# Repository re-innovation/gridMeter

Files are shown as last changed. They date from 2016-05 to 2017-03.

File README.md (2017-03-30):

# gridMeter
A National Grid frequency monitor for visualising power flows on the national grid

# Overview

# Collaborators
* James Fowkes - Software and PCB design v1
* Matt Little - PCB design v2 and Hardware

# PCB
This holds the PCB files done using KiCAD
http://kicad-pcb.org/

# Software
This holds the software. Uploaded via the Arduino IDE.
This is programmed to an ATTiny84
It requires

# Hardware
This holds the mechanical files for the enclosure.

# To DO

- Update PCB design with changes
- Enclosure design - version 1 done

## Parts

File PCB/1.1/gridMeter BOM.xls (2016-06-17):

Reference | Quantity | Value | Footprint | Datasheet | Manufacturer | Manufacturer Part No | Supplier 1 | Supplier 1 Part No | Cost | Description
C1 C4 C5 | 3 | 100n | Capacitors_ThroughHole:C_Rect_L7_W2.5_P5
C2 C3 | 2 | 220u | Capacitors_ThroughHole:C_Radial_D6.3_L11.2_P2.5
CON1 | 1 | AC POWER | REInnovationFootprint:DC_Power_2_1 | http://www.rapidonline.com/pdf/20-0970.pdf | TruConnect |  | Rapid | 20-0970 | 0.19 | 2.1mm Barrell Jack
D1 D2 D3 D4 D5 D6 | 6 | 1N400x | Diodes_ThroughHole:Diode_DO-41_SOD81_Horizontal_RM10
IC1 | 1 | ATTINY84A-PU | Housings_DIP:DIP-14_W7.62mm | http://docs-europe.electrocomponents.com/webdocs/0fa2/0900766b80fa26b4.pdf | Atmel | ATTINY84A-PU | RS | 738-0684 | 1.05
P1 | 1 | STEPPER
P2 | 1 | AC POWER | REInnovationFootprint:TH_CONN_2W
P3 | 1 | MOTOR | gridMeter:XHP-5
P4 | 1 | ISP | Pin_Headers:Pin_Header_Straight_2x03
P5 | 1 | PCB
P6 | 1 | LOGO1 | CuriousElectric2:CuriousElectric_flat_12mm
P7 | 1 | Enclosure
P8 | 1 | LOGO2 | CuriousElectric2:CuriousElectric_globe_10mm
R2 | 1 | 330R | Resistors_ThroughHole:Resistor_Horizontal_RM10mm
R1 R3 R4 | 3 | 10K | Resistors_ThroughHole:Resistor_Horizontal_RM10mm
U1 | 1 | MCP170-3_3V | matts_components:TO92-MCP1700 | http://docs-europe.electrocomponents.com/webdocs/137e/0900766b8137eacf.pdf | Microchip | MCP1700-3302E/TO | RS | 403-888 | 0.253 | LDO 3.3V 100mA
U2 | 1 | TCXO_SMD_4P | gridMeter:FOX924 |  | Fox | FOX924B-16.000 | Aliexpress | http://www.aliexpress.com/item/Hot-selling-original-15PCS-FOX924B-16-000-Oscillator-TCXO-16MHz-1-5ppm-2-5ppm-Stability/32668179196.html | 0.6 | 12MHz TCO SMD
U3 | 1 | TCRT5000 | gridMeter:TCRT5000 |  |  | TCRT5000L | Aliexpress | http://www.aliexpress.com/item/Free-Shipping-100-pcs-TCRT5000L-TCRT5000-Reflective-Infrared-Optical-Sensor-Photoelectric-Switches/1933011720.html | 0.15 | Opto-reflective IR sensor
U4 | 1 | 7805 | TO_SOT_Packages_THT:TO-220_Neutral123_Horizontal | http://docs-europe.electrocomponents.com/webdocs/12cf/0900766b812cfcbe.pdf | Fairchild | LM7805ACT | RS | 806-2839 | 0.327 | 1A 5V regulator.
U5 | 1 | ULN2003 | Housings_DIP:DIP-16_W7.62mm_LongPads | http://docs-europe.electrocomponents.com/webdocs/1294/0900766b81294fa6.pdf | Toshiba | ULN2003APG | RS | 796-5320 | 0.151 | Darlington transistor array

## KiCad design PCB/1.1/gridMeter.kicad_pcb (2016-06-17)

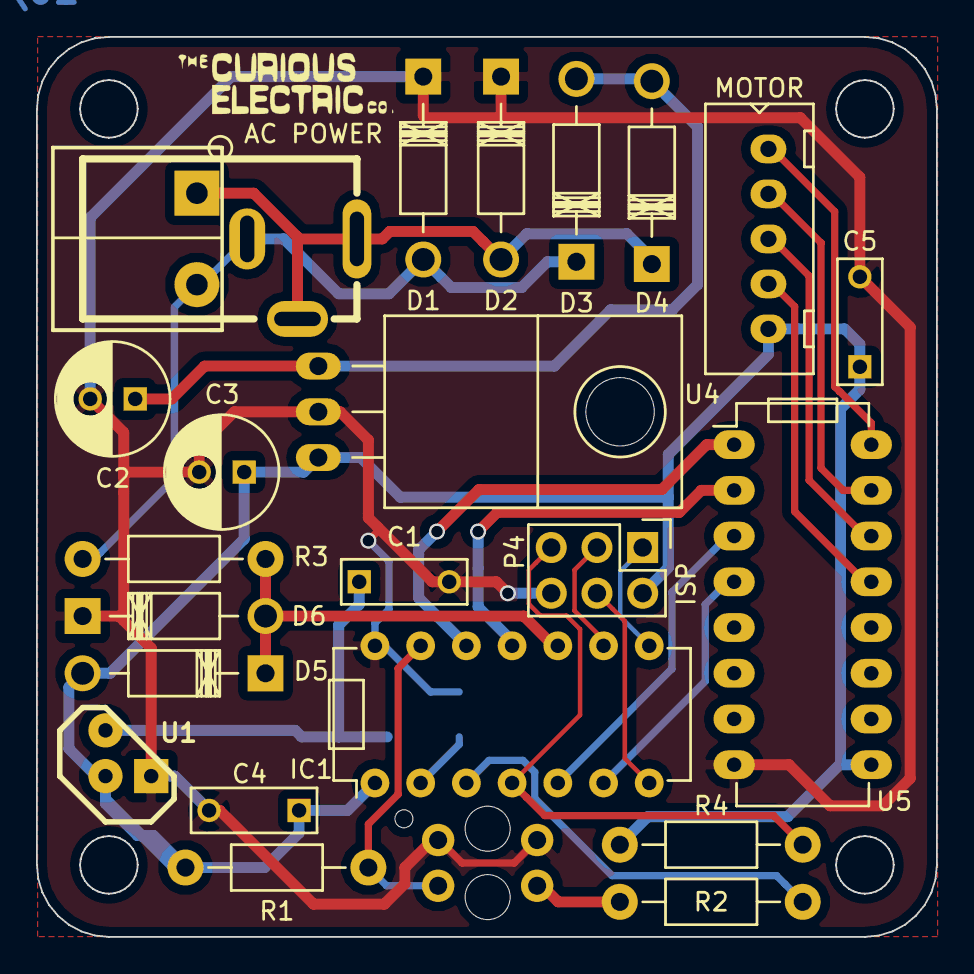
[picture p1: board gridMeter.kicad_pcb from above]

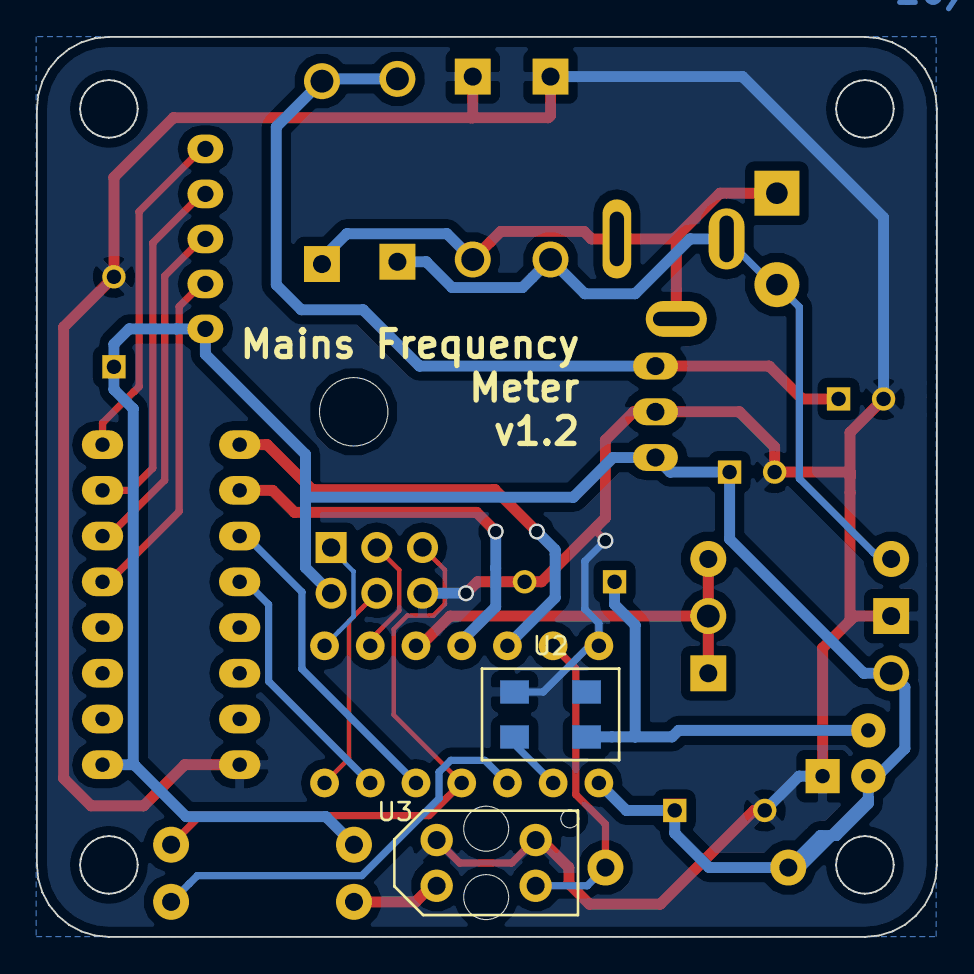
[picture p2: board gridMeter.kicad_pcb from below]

Board: 2 copper layers, 50.0 x 50.0 mm, 26 parts (2 on the bottom side), 23 nets.

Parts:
C1, C4, C5: 100n; C_Rect_L7_W2.5_P5
C2, C3: 220u; C_Radial_D6.3_L11.2_P2.5
CON1: AC POWER; DC_Power_2_1
D1, D2, D3, D4, D5: IN400x; Diode_DO-41_SOD81_Horizontal_RM10
D6: 1N400x; Diode_DO-41_SOD81_Horizontal_RM10
IC1: ATTINY84A-PU; DIP-14_W7.62mm
P2: AC POWER; TH_CONN_2W
P3: MOTOR; XHP-5
P4: ISP; Pin_Header_Straight_2x03
P6: LOGO1; CuriousElectric_flat_12mm
R1, R3, R4: 10K; Resistor_Horizontal_RM10mm
R2: 330R; Resistor_Horizontal_RM10mm
U1: MCP170-3_3V; TO92-MCP1700
U2: TCXO_SMD_4P; FOX924
U3: TCRT5000
U4: 7805; TO-220_Neutral123_Horizontal
U5: ULN2003; DIP-16_W7.62mm_LongPads

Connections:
/DMAINSF: D5.1, D6.2, IC1.10, R3.1
/IN1: IC1.12, U5.1
/IN2: IC1.11, U5.2
/IN3: IC1.5, U5.3
/IN4: IC1.6, U5.4
/MAINSF: CON1.1, D1.2, D3.1, P2.2, R3.2
/MISO: IC1.8, P4.1
/MOSI: IC1.7, P4.4
/MOTOR_HOME_OUT: IC1.3, R2.1
/MOTOR_HOME_SENSE: IC1.13, R1.1, U3.1
/RST: IC1.4, P4.5, R4.1
/SCK: IC1.9, P4.3
/TCXO: IC1.2, U2.3
GND: C1.2, C2.2, C3.2, C4.2, C5.2, D1.1, D2.1, D6.1, IC1.14, P4.6, U1.GND, U2.2, U3.2, U3.3, U4.2, U5.8
unnamed: C1.1, U1.VO, U2.4
unnamed: C2.1, D3.2, D4.2, U4.1
unnamed: CON1.2, CON1.3, D2.2, D4.1, P2.1
unnamed: P3.1, U5.16
unnamed: P3.2, U5.15
unnamed: P3.3, U5.14
unnamed: P3.4, U5.13
unnamed: R2.2, U3.4
VCC: C3.1, C4.1, C5.1, D5.2, IC1.1, P3.5, P4.2, R1.2, R4.2, U1.VI, U4.3, U5.9

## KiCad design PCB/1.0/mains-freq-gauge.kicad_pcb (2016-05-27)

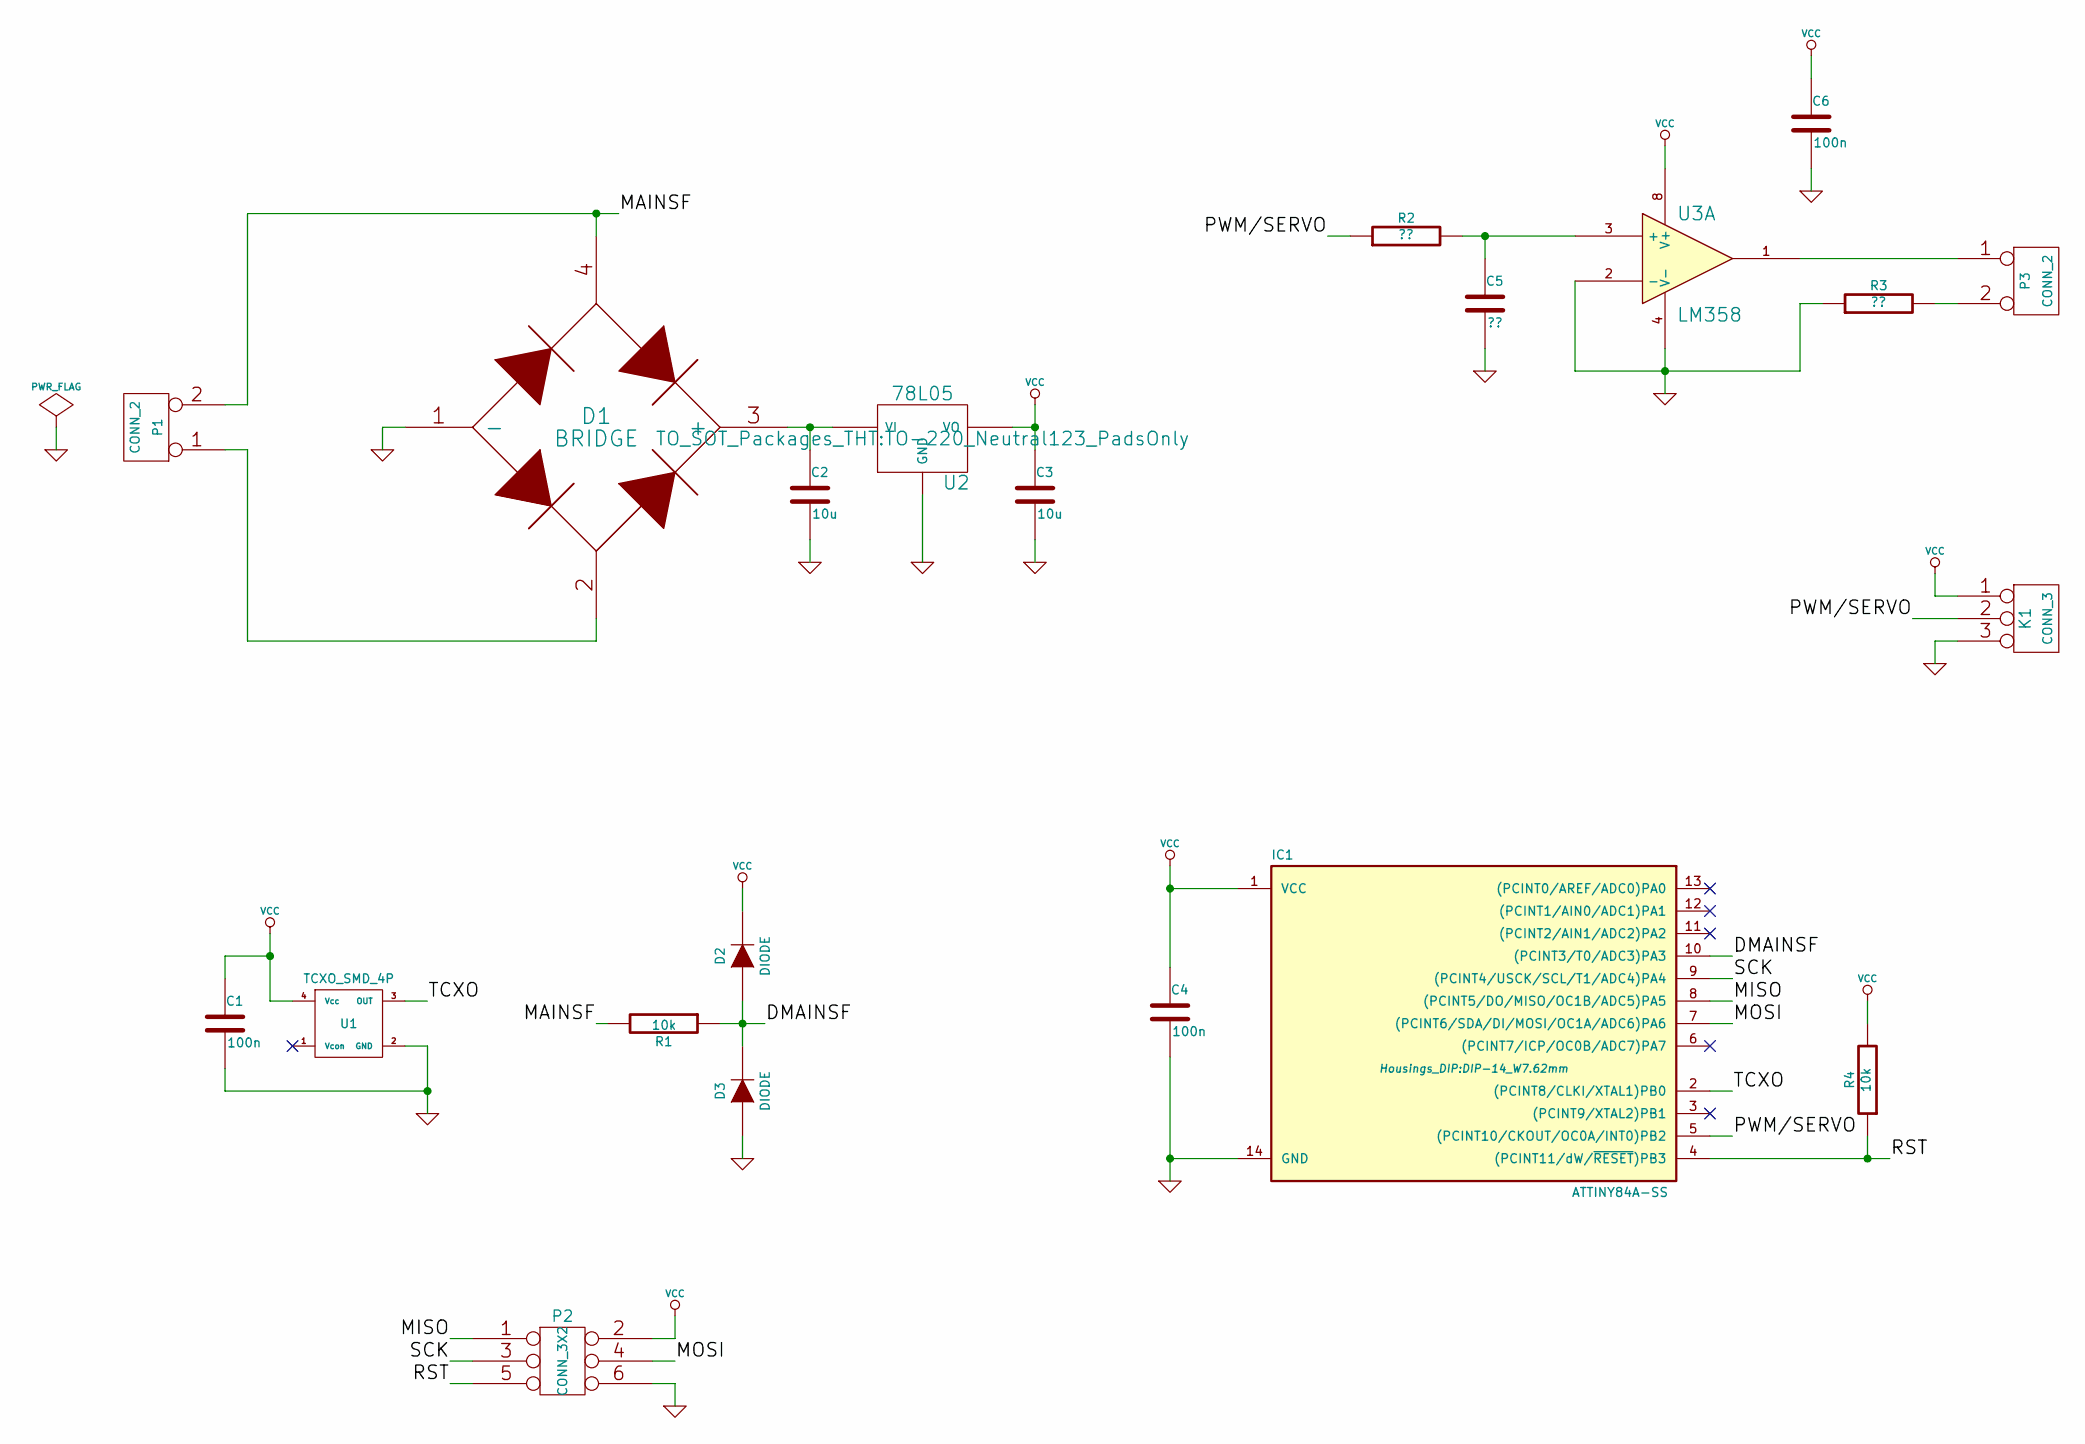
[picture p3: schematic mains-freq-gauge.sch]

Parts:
C1, C4, C6: 100n; C_Rect_L4_W2.5_P2.5
C2, C3: 10u; C_Radial_D5_L11_P2.5
C5: ??; C_Rect_L4_W2.5_P2.5
D1: BRIDGE; WOB
D2, D3: DIODE; Diode_DO-41_SOD81_Horizontal_RM10
IC1: ATTINY84A-SS; DIP-14_W7.62mm
K1: CONN_3; Pin_Header_Straight_1x03
P1, P3: CONN_2; Pin_Header_Straight_1x02
P2: CONN_3X2; Pin_Header_Straight_2x03
R1, R4: 10k; Resistor_Horizontal_RM15mm
R2, R3: ??; Resistor_Horizontal_RM15mm
U1: TCXO_SMD_4P; TG5006CG
U2: 78L05; TO-220_Neutral123_PadsOnly
U3: LM358; DIP-8_W7.62mm

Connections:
/DMAINSF: D2.1 (A), D3.2 (K), IC1.10 ((PCINT3/T0/ADC3)PA3), R1.1
/MAINSF: D1.4, P1.2 (PM), R1.2
/MISO: IC1.8 ((PCINT5/DO/MISO/OC1B/ADC5)PA5), P2.1
/MOSI: IC1.7 ((PCINT6/SDA/DI/MOSI/OC1A/ADC6)PA6), P2.4
/PWM/SERVO: IC1.5 ((PCINT10/CKOUT/OC0A/INT0)PB2), K1.2 (PM), R2.1
/RST: IC1.4 ((PCINT11/dW/~RESET~)PB3), P2.5, R4.1
/SCK: IC1.9 ((PCINT4/USCK/SCL/T1/ADC4)PA4), P2.3
/TCXO: IC1.2 ((PCINT8/CLKI/XTAL1)PB0), U1.3 (OUT)
GND: C1.2, C2.2, C3.2, C4.2, C5.2, C6.2, D1.1 (-), D3.1 (A), IC1.14 (GND), K1.3, P2.6, R3.1, U1.2 (GND), U2.2 (GND), U3.2 (-), U3.4 (V-)
unnamed: C2.1, D1.3 (+), U2.3 (VI)
unnamed: C5.1, R2.2, U3.3 (+)
unnamed: D1.2, P1.1
unnamed: P3.1, U3.1
unnamed: P3.2 (PM), R3.2
VCC: C1.1, C3.1, C4.1, C6.1, D2.2 (K), IC1.1 (VCC), K1.1, P2.2, R4.2, U1.4 (Vcc), U2.1 (VO), U3.8 (V+)

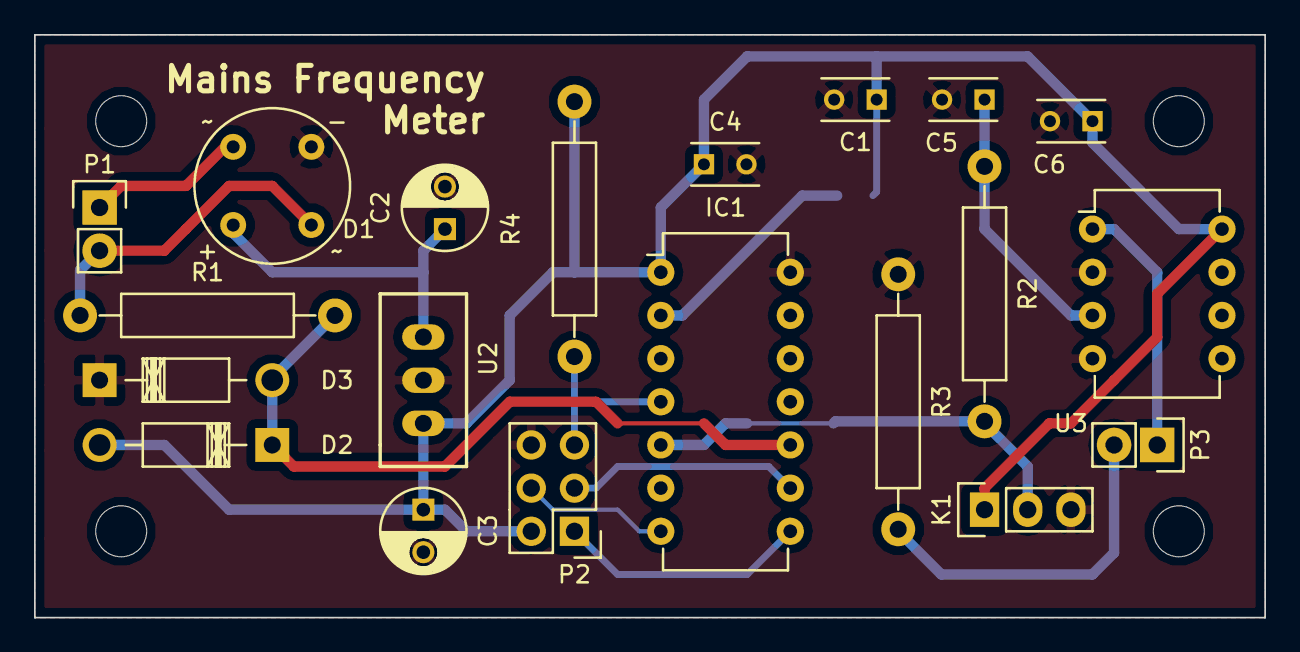
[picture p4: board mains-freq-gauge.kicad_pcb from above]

Board: 2 copper layers, 72.4 x 34.3 mm, 21 parts (1 on the bottom side), 15 nets.

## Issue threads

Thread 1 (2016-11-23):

Diodes silkscreen on PCB

re-innovation, 2016-11-23:
The diodes on the silkscreen are the wrong way around. Need PCB to be updated

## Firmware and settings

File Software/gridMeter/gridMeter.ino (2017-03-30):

/*
 * gridMeter,ino
 *
 * Author: James Fowkes (jamesfowkes@gmail.com)
 * for The Curious Electric Company (https://www.curiouselectric.co.uk)
 *
 * March 2017
 *
 * Target microcontroller is an ATTINY(2/4/8)4A.
 * This program accurately determines the frequency of the "mains" (national grid)
 * and displays it.
 * 
 * Frequency determination is done by counting ticks of a reference timer over
 * a fixed number of mains cycles. This number is then used to determine the frequency
 * of the mains input.
 *
 * For example, if a 250kHz reference is used, and the mains is counted over 50 cycles:
 *  - The expected number of counts if the frequency is exactly 50.000Hz is 250000.
 *  - If the frequency were only 49.960Hz, the count would be 250000 * (50/49.960) = 250200
 *
 * The reference clock must be very stable and accurate for the final result to
 * be meaningful. Therefore a TCXO or other such source should be used.
 *
 */

/*
 * AVR/Arduino Library Includes
 */

#include <SoftwareSerial.h>

/*
 * Application Includes
 */

#include "indicator.h"
#include "stepper.h"

/*
 * Defines and Typedefs
 */

#define MAINS_FREQ_INPUT_PIN (3) // Arduino digital pin 3 = physical pin 10, PA3)
#define TX_PIN (5) // Arduino digital pin 5 = physical pin 8, PA5)
#define RX_PIN (6) // Arduino digital pin 6 = physical pin 7, PA6)

// Timer1 counts pulses from TCXO (which is FCPU)
// Select FCPU/64 as Timer1 clock, for a 250kHz reference
#define TMR1_CLK_FREQ_BITS ((1 << CS11) | (1 << CS10))
#define TMR1_CLK_FREQ (F_CPU/64)

/*
 * Module private objects and variables
 */

// This variable stores the number of reference timer ticks
static volatile uint32_t s_tmr_counts;

static const uint8_t IDEAL_SECONDS = 1;  // How seconds we should be counting for
static const uint8_t IDEAL_F_MAINS = 50;  // Ideal mains frequency
static const uint8_t IDEAL_CYCLES = IDEAL_F_MAINS * IDEAL_SECONDS;  // The number of mains cycles to count

// All maths is fixed point, so multiply final result by 1000 (e.g. 50.124Hz is stored as 50124)
static const uint32_t FIXED_POINT_MULTIPLIER = 1000;

static const uint32_t IDEAL_F_CLK = TMR1_CLK_FREQ; // Frequency of the incoming clock
static const uint32_t IDEAL_F_CLK_COUNTS = IDEAL_SECONDS * IDEAL_F_CLK;  // If mains is exactly 50Hz, should count exactly this many clocks in time period

// Software serial is used for debugging - outputs frequency every second
SoftwareSerial s_serial(RX_PIN, TX_PIN); // RX, TX (physical pins 11, 12)

/*
 * Module private functions
 */

/* output_to_serial
 * Print "output" wth the given printf format, with or without newline
 */
static void output_to_serial(uint32_t output, char const * const fmt, bool newline = false)
{
	char buf[16];
	sprintf(buf, fmt, output);

	if (newline)
	{
		s_serial.println(buf);
	}
	else
	{
		s_serial.print(buf);
	}
}

/* output_freq_to_serial
 * Print frequency after removing fixed point multiplier, with or without newline
 */
static void output_freq_to_serial(uint32_t freq, bool newline = false)
{
	uint32_t units = freq / FIXED_POINT_MULTIPLIER;

	output_to_serial(units, "%lu", false);
	s_serial.print(".");
	output_to_serial(freq - (units  * FIXED_POINT_MULTIPLIER), "%03d",false);

	if (newline)
	{
  	s_serial.println("Hz");
  }
  else
  {
  	s_serial.print("Hz");	
  }
}

/* calculate_frequency
 * Convert counts to frequency (fixed point maths)
 */
static uint32_t calculate_frequency(uint32_t counts)
{
  // Adding counts/2 ensures correct rounding after dvision
  uint64_t freq = ((uint64_t)IDEAL_F_CLK_COUNTS * FIXED_POINT_MULTIPLIER * IDEAL_F_MAINS) + (counts/2);
  return freq / counts;
}

/* Called every loop: process the timer count and output frequency */
static void process_count(uint32_t count)
{
	output_to_serial(count, "%lu", false);
	s_serial.print(" = ");
  uint32_t freq = calculate_frequency(count);
  output_freq_to_serial(freq, true);
  indicator_moveto_freq(freq, TCNT1);
}

/* setup_timer
 * The 16-bit timer is used in free-running mode, no special features except the overflow interrupt
 */
static void setup_timer()
{
  // Set prescaler at div.1 (ensures system clock is 16MHz)
  CLKPR = (1 << CLKPCE);
  CLKPR = (0 << CLKPCE);

  // Disable all 16-bit timer functions
  TCCR1A = 0;
  TCCR1C = 0;
  
  // Set 16-bit timer source
  TCCR1B = TMR1_CLK_FREQ_BITS;

  // Enable 16-bit timer overflow interrupt
  TIMSK1 = (1 << TOIE1);

}

static void disable_watchdog()
{
  MCUSR = 0x00;
  WDTCSR |= (1<<WDCE) | (1<<WDE);
  WDTCSR = 0x00;
}

static void setup_io()
{
  pinMode(MAINS_FREQ_INPUT_PIN, INPUT);
}

/* sync_with_mains_falling_edge
 * wait_for_mains_input_to_be_high
 * wait_for_mains_input_to_be_low
 * wait_for_mains_periods
 * In order to accurately count frequency, counting code must syncronise with the mains input.
 * These functions perform that task.
 */
static void sync_with_mains_falling_edge()
{
  wait_for_mains_input_to_be_high();
  wait_for_mains_input_to_be_low();
}

static void wait_for_mains_input_to_be_high()
{
  while(digitalRead(MAINS_FREQ_INPUT_PIN) == LOW) {
    indicator_tick(TCNT1); // Keep the motor moving
  }
  // The digital read change occurs 1ms before the rising edge
  _delay_ms(1);
}

static void wait_for_mains_input_to_be_low()
{
  while(digitalRead(MAINS_FREQ_INPUT_PIN) == HIGH) {
    indicator_tick(TCNT1);  // Keep the motor moving
  }
  // The digital read change occurs 1ms before the falling edge
  _delay_ms(1);
}

static void wait_for_mains_periods(uint16_t counts)
{
  while(counts)
  {
    sync_with_mains_falling_edge();
    counts--;   
  }
}

/* get_count
 * Called every loop. Waits for mains cycles, and counts reference clocks. */

static uint32_t get_count()
{
  sync_with_mains_falling_edge();

  TCNT1 = 0;
  s_tmr_counts = 0;

  wait_for_mains_periods(IDEAL_CYCLES);

  return s_tmr_counts + TCNT1;
}

/*
 * Public functions
 */

void setup() {

  // Ensure the watchdog will not reset the microcontroller
  disable_watchdog();

  // Enable the serial debugging output
  s_serial.begin(9600);

  // Setup the microcontroller peripherals
  setup_io();
  setup_timer();

  // Ask the indicator module to set itself up and home if needed
  indicator_setup();
  indicator_home();

  // "Self-test" the indicator by moving to its limit then back to centre
  indicator_moveto_freq_blocking(MAX_FREQ_LIMIT);
  indicator_moveto_freq_blocking(MIN_FREQ_LIMIT);
  indicator_moveto_freq_blocking(50000);
}

void loop() {
  // Very simple loop: get the count and display it!
  uint32_t count = get_count();
  process_count(count);
}

ISR(TIM1_OVF_vect)
{
  // The reference clock is counted on the 16-bit timer.
  // Each time it overflows, save another 16-bits of count,
  // which is 65536.
  s_tmr_counts += 65536;
}

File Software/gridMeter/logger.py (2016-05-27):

"""Usage:
	logger.py <port> [--timeout=seconds]

"""

from docopt import docopt
import serial
import datetime

def start_logging(port):
	with serial.Serial(port, 9600) as ser:
		while(True):
			line = ser.readline()
			print("{}, {}".format(datetime.datetime.now(), line.decode("utf-8").strip()))

if __name__ == "__main__":
	args = docopt(__doc__)
	start_logging(args["<port>"])

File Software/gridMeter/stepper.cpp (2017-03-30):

/*
 * stepper.cpp
 *
 * Provides low level stepper functionality.
 * Basic functionality copied from standard stepper 
 * library to save program space and allow enable/disable
 *
 */

#include <Arduino.h>

#include "stepper.h"

#define SPEED_IN_RPM 1

#define STEP_DELAY (60L * 1000L * 1000L / STEPS_PER_REV / SPEED_IN_RPM)

Stepper::Stepper(int motor_pin_1, int motor_pin_3, int motor_pin_2, int motor_pin_4)
{
  this->step_number = 0;    // which step the motor is on
  this->direction = 0;      // motor direction
  this->last_step_time = 0; // time stamp in us of the last step taken

  // Arduino pins for the motor control connection:
  this->motor_pin_1 = motor_pin_1;
  this->motor_pin_2 = motor_pin_2;
  this->motor_pin_3 = motor_pin_3;
  this->motor_pin_4 = motor_pin_4;

  // setup the pins on the microcontroller:
  pinMode(this->motor_pin_1, OUTPUT);
  pinMode(this->motor_pin_2, OUTPUT);
  pinMode(this->motor_pin_3, OUTPUT);
  pinMode(this->motor_pin_4, OUTPUT);
}

/*
 * Moves the motor steps_to_move steps.  If the number is negative,
 * the motor moves in the reverse direction.
 */
void Stepper::step(int steps_to_move)
{
  int steps_left = abs(steps_to_move);  // how many steps to take

  // determine direction based on whether steps_to_mode is + or -:
  if (steps_to_move > 0) { this->direction = 1; }
  if (steps_to_move < 0) { this->direction = 0; }


  // decrement the number of steps, moving one step each time:
  while (steps_left > 0)
  {
    // increment or decrement the step number,
    // depending on direction:
    if (this->direction == 1)
    {
      this->step_number++;
      if (this->step_number == STEPS_PER_REV) {
        this->step_number = 0;
      }
    }
    else
    {
      if (this->step_number == 0) {
        this->step_number = STEPS_PER_REV;
      }
      this->step_number--;
    }
    
    // decrement the steps left:
    steps_left--;
    stepMotor(this->step_number % STEP_LIMIT);
    if (steps_left) { _delay_us(STEP_DELAY); }

  }
}

void Stepper::enable()
{
  if (!this->_enabled)
  {
    this->_enabled = true;
    stepMotor(this->step_number % STEP_LIMIT);
  }
}

void Stepper::disable()
{
  if (this->_enabled)
  {
    this->_enabled = false;
    digitalWrite(motor_pin_1, LOW);
    digitalWrite(motor_pin_2, LOW);
    digitalWrite(motor_pin_3, LOW);
    digitalWrite(motor_pin_4, LOW);
  }
}

bool Stepper::enabled() { return this->_enabled; }

/*
 * Moves the motor forward or backwards (quarter stepping)
 */

void Stepper::stepMotor(int thisStep)
{
  switch (thisStep) {
    case 0:
      digitalWrite(motor_pin_1, HIGH);
      digitalWrite(motor_pin_2, LOW);
      digitalWrite(motor_pin_3, LOW);
      digitalWrite(motor_pin_4, LOW);
    break;
    case 1:
      digitalWrite(motor_pin_1, HIGH);
      digitalWrite(motor_pin_2, HIGH);
      digitalWrite(motor_pin_3, LOW);
      digitalWrite(motor_pin_4, LOW);
    break;
    case 2:
      digitalWrite(motor_pin_1, LOW);
      digitalWrite(motor_pin_2, HIGH);
      digitalWrite(motor_pin_3, LOW);
      digitalWrite(motor_pin_4, LOW);
    break;
    case 3:
      digitalWrite(motor_pin_1, LOW);
      digitalWrite(motor_pin_2, HIGH);
      digitalWrite(motor_pin_3, HIGH);
      digitalWrite(motor_pin_4, LOW);
    break;
    case 4:
      digitalWrite(motor_pin_1, LOW);
      digitalWrite(motor_pin_2, LOW);
      digitalWrite(motor_pin_3, HIGH);
      digitalWrite(motor_pin_4, LOW);
    break;
    case 5:
      digitalWrite(motor_pin_1, LOW);
      digitalWrite(motor_pin_2, LOW);
      digitalWrite(motor_pin_3, HIGH);
      digitalWrite(motor_pin_4, HIGH);
    break;
    case 6:
      digitalWrite(motor_pin_1, LOW);
      digitalWrite(motor_pin_2, LOW);
      digitalWrite(motor_pin_3, LOW);
      digitalWrite(motor_pin_4, HIGH);
    break;
    case 7:
      digitalWrite(motor_pin_1, HIGH);
      digitalWrite(motor_pin_2, LOW);
      digitalWrite(motor_pin_3, LOW);
      digitalWrite(motor_pin_4, HIGH);
    break;
  }
}

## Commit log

2016-05-27 Initial PCB and software commit
    [mains-freq-gauge.kicad_pcb, mains-freq-gauge.sch]
2016-06-06 PCB version 1.1
    [gridMeter.kicad_pcb, gridMeter.sch, mains-freq-gauge.kicad_pcb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]
2016-06-10 Changes to Schematic PCB Gerbers
    Matt Little changes to components - added different values and suppliers
    codes. Slight change to PCB and footprints. Added Logo to silkscreen.
    [gridMeter.kicad_pcb, gridMeter.sch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]
2016-06-17 Final changes before PCB run 1
    [gridMeter BOM.xls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]
2017-03-07 Add homing code, switch to half stepping
2017-03-20 Add movement deadzone and stepper disable
2017-03-30 Add homing, movement deadzone stepper enable/disable
